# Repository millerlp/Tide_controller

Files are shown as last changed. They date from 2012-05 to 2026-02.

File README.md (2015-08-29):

Tide_controller
===============

Arduino code and associated files for building an aquarium tide height controller. This assumes that you 
have downloaded and installed the latest version of the Arduino software (v1.6.4, or newer).

Installation:

To operate the tide controller rack, install the following:

1. Install a copy of RTClib in your Arduino/libraries/ directory. If there is not already a libraries directory, create it now. RTClib can be downloaded from https://github.com/millerlp/RTClib. If the copy you download and unzip is called "RTClib-master", rename the folder to simply be "RTClib".

2. Copy the folder with the tide library for your site (i.e. TidelibSanDiegoSanDiegoBay) into Arduino/libraries/

3. Copy the Tide_controller_v2_5 folder (or most recent version) into your Arduino folder where 
your other sketches are normally stored. 

4. Open the Tide_controller sketch in the Arduino IDE, and make sure the correct tide site
library is referenced in the Initial Setup section, near line 57, with a line like:

	\#include "TidelibSanDiegoSanDiegoBay.h"

That line should contain the name of the library for your local site that you copied into Arduino/libraries/.

5. If you want to change the tide range in which the tide rack travels, you can change the
value for the upperPos on or around line 64, which looks like:
	float upperPos = 5.0;
That line represents the upper limit at which the tide rack will stop moving upward, even
if the predicted tide goes higher. The units of upperPos are feet (not meters or inches). 

Plug the Arduino in to the computer using a USB cable. Upload the program to the Arduino. 
Open the serial monitor to view the output. See the http://arduino.cc site for help with 
these steps. 

------------------------------
If the real time clock attached to the Arduino is not yet set, you need to set it one time
before loading the tide prediction software onto the Arduino. Open the Arduino software and 
go to File>Examples>RTClib>settime_exact.ino. Follow the instructions at the top of
that sketch to upload the correct time to your real time clock. Make sure the time you enter
is in your local standard time, not Daylight Savings Time (which runs Mar-Nov
in most places). The tide prediction routine relies on the time being set to local 
standard time for your site, otherwise you won't get the current tide height out. After running
the settime_exact.ino sketch, before unplugging the Arduino, immediately upload a different 
sketch (such as the Tide_controller sketch) to the Arduino so that the clock doesn't try to reset 
itself repeatedly when the Arduino restarts.

-------------------------------
If there is no folder containing a tide prediction library for your desired site, it
will be necessary to generate a library using the R scripts found in the 
Generate_new_site_libraries directory. The harmonic data for NOAA sites are all in
the Harmonics_20120302.Rdata file. With these data, you can generate a new library
by running the R script tide_harmonics_library_generator.R. Inside that file, you must
enter a name for the site you're interested in on the line
stationID = 'Monterey Harbor'
Change the value inside the quote marks to match your site, save the file, and run the
script in R. It will create a new directory with the necessary library files inside that
can be copied into the Arduino/libraries/ folder. Find the name for your site by looking 
through the XTide website http://www.flaterco.com/xtide/locations.html 
XTide only produces harmonics for 635 reference tide stations (all others are approximated 
from these tide stations), so you need to find the nearest station listed as "Ref" on that 
page, rather than "Sub" stations.

The other R scripts in the Generate_new_site_libraries directory could be used to make an
updated Rdata file when XTide updates the original harmonics database and after you
convert it to a text file using the libtcd library from the XTide site (see the notes inside
the R scripts).

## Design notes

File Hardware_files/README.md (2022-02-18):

Tide_controller/Hardware_files

A add-on 'shield' designed to be used with an Arduino Uno was designed for this
project. The shield provides mounting points for the real time clock (DS3231),
buttons, indicator LEDs, resistors, and connectors to interface with the stepper 
motor controller and displays. 

See the file 'Tide_shield_notes.pdf' for more information on how this shield
is meant to be wired and used. 

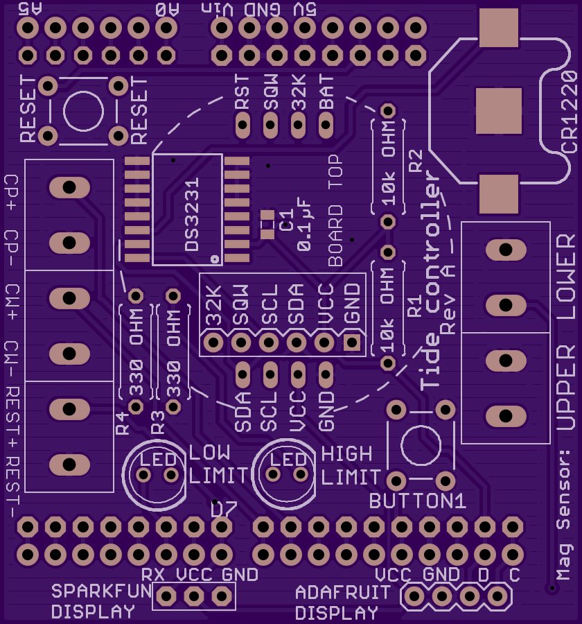
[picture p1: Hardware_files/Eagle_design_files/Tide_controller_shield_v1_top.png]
board image


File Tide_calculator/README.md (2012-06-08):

Tide_calculator.ino
Luke Miller, June 2012

This Arduino sketch is an example of a stand-alone tide height calculator. It doesn't 
do anything besides calculate a new tide height once per minute and output that
value to the Arduino's serial monitor (set your baud rate to 115200). This can 
be used as the basis for creating more complicated projects that need an 
accurate tide height calculation.

The calculations are only made for a single pre-programmed site, so if you need 
projections for a different NOAA tide site, you need to modify the Amplitude (Amp)
and Kappa arrays, preferrably using the R script files provided in the github 
repository. 

In addition to the basic Arduino, the only other required piece of hardware is a 
real time clock, based on the DS1307 or DS3231 chips, connected to analog pins
4 + 5 for the I2C interface (on traditional Arduinos such as the Uno). The routine
needs a current date and time to correctly make predictions. If used for sites outside
of the Pacific Standard Time zone, you'll also need to modify the value of adjustGMT 
inside the sketch.

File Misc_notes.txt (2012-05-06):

Arduino ports:

B: digital pin 8 to 13, covered by PCINT0
C: analog input pins, 	covered by PCINT1
D: digital pins 0 to 7, covered by PCINT2

Modified mySoftwareSerial.cpp to comment out lines:

/*
#if defined(PCINT1_vect)
ISR(PCINT1_vect)
{
  SoftwareSerial::handle_interrupt();
}
#endif

#if defined(PCINT2_vect)
ISR(PCINT2_vect)
{
  SoftwareSerial::handle_interrupt();
}
#endif

#if defined(PCINT3_vect)
ISR(PCINT3_vect)
{
  SoftwareSerial::handle_interrupt();
}
#endif
*/

so that mySoftwareSerial doesn't interfere with other routines trying to
use pin change interrupts on ports C and D. mySoftwareSerial retains use 
of pin change interrupts on port B (digital pins 8-13).
This leaves ports C and D available for routines like the PololuWheelEncoders.
See http://baldwisdom.com/we-interrupt-our-regular-programming/

The code in PololuWheelEncoders.cpp also needs to be modified. The line
ISR(PCINT0_vect) 
should be changed to read ISR(PNINT2_vect), and the two lines

ISR(PCINT1_vect,ISR_ALIASOF(PCINT0_vect));
ISR(PCINT2_vect,ISR_ALIASOF(PCINT0_vect));

below that should be commented out. This will make it so that the encoder
functions only work on digital lines 0-7 (Arduino PortB).

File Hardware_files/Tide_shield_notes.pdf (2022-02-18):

A design for a printed circuit board to mount to a standard Arduino Uno microcontroller is provided here. This is often referred to as a “shield”. The design files were created with Cadsoft Eagle 7.2, and be found in the online archive associated with this project,

### http://purl.stanford.edu/rb471wt3944 as the compressed archive

“Tide_controller_circuit_board_files.tar”. The Eagle files can be used to generate files that many online printed circuit board manufacturers can use to produce this board.

The shield is designed to interface with a CW230 stepper motor controller, two magnetic reed switches, and a real time clock. There are three different options available for real time clocks on the shield, depending on the user’s desire and available parts. Two places for indicator LEDs are provided, along with buttons to reset the Arduino and a button to control the tide rack behavior (BUTTON1). The individual parts are indicated in the following sections.


Figure 1. The top side of the tide controller shield.

## Connectors for CW230 stepper motor controller and magnetic reed switches

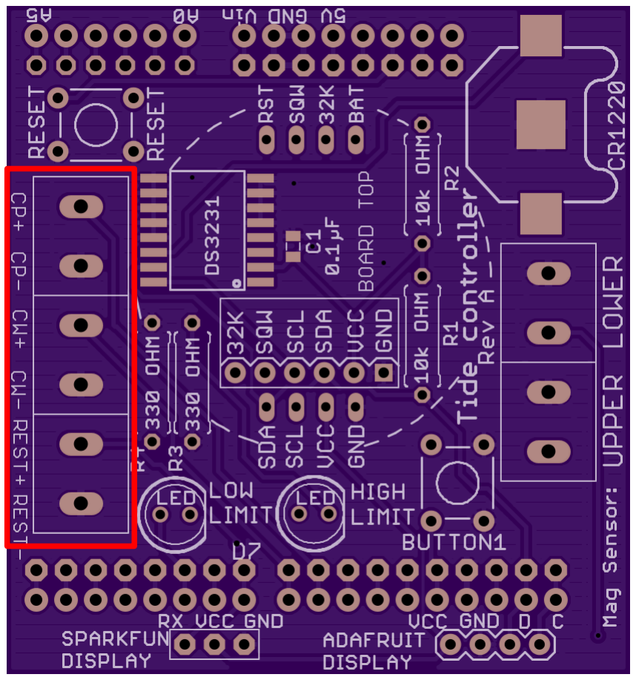
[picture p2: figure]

Figure 2. Positions for terminal blocks (highlighted in red) are provided to hook wires to the CW230 stepper motor controller. The labels here match the labels used on the CW230.

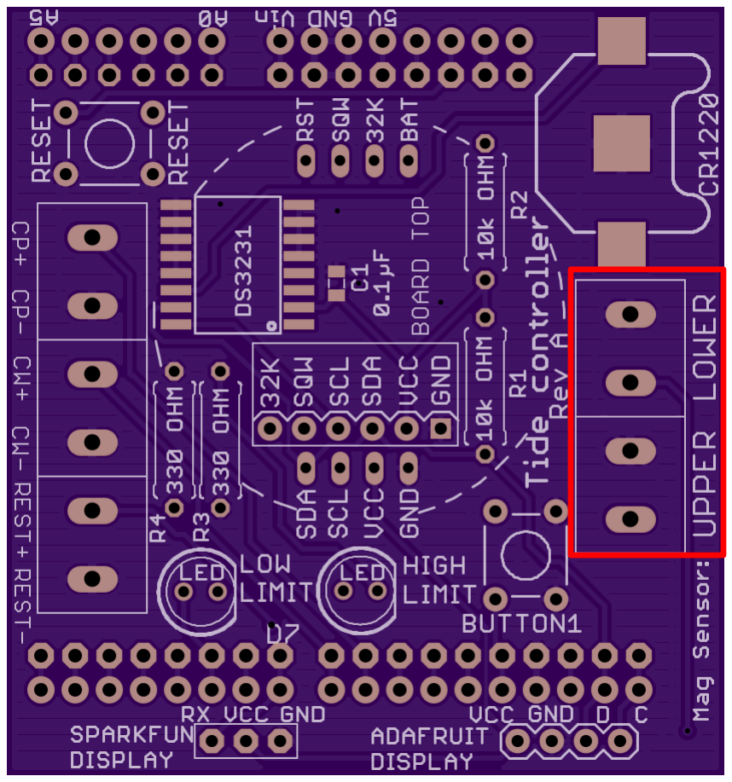
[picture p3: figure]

Figure 3. Positions for terminal blocks (highlighted in red) are provided to hook wires to two separate magnetic reed switches to be mounted on the frame of the tide rack. These set the upper and lower travel limits of the rack carriage, and are actuated by a magnet attached to the rack carriage. The polarity of the wires on these terminals does not matter, they are simple open/closed switches.

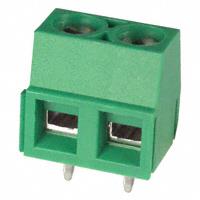
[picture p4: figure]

Figure 4. Terminal blocks that will fit in the shield. These are available from several manufacturers. The pictured unit is from On Shore Technology Inc, part number EDZ250/2.

## LED indicators

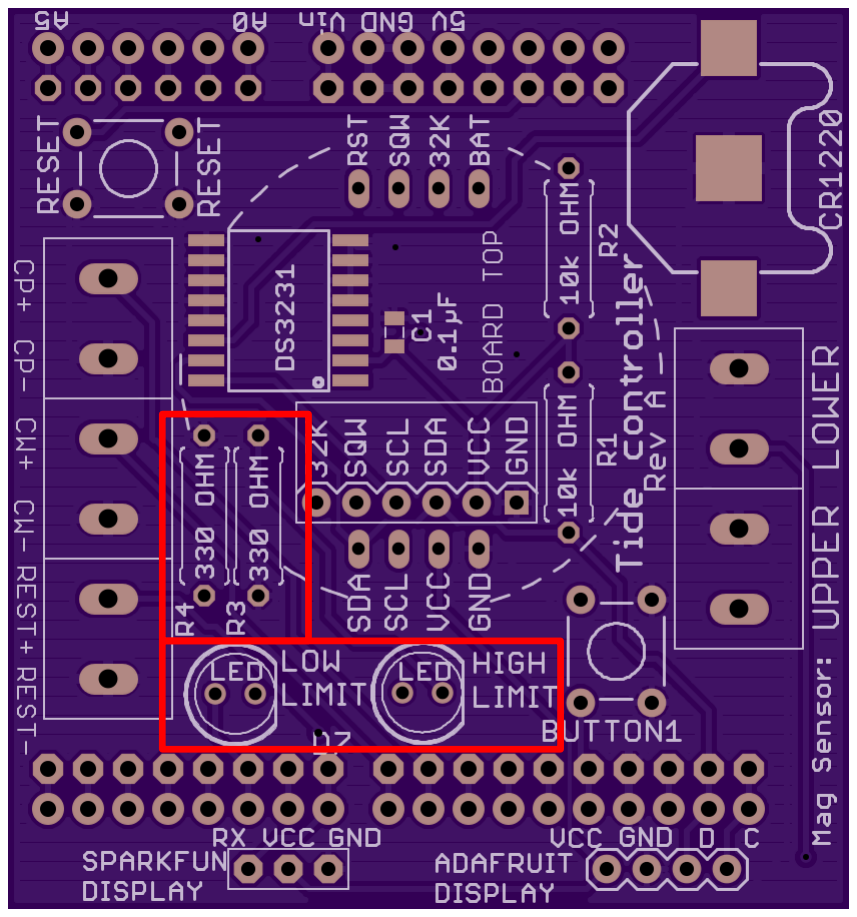
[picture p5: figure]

Figure 5. Positions for two LEDs, and their associated resistors are highlighted in red. A resistor value between 100ohm and 330ohm is sufficient. The LEDs fit standard 5mm (T 1-3/4) size LEDs. The low limit or high limit LED lights when the associated magnetic limit switch is activated. LED options from Lite-On include a red version LTL-307EE and a green version LTL-307GE. Resistors can be generic, such as Stackpole CF18JT330R 330 ohm 1/8Watt.

## Buttons

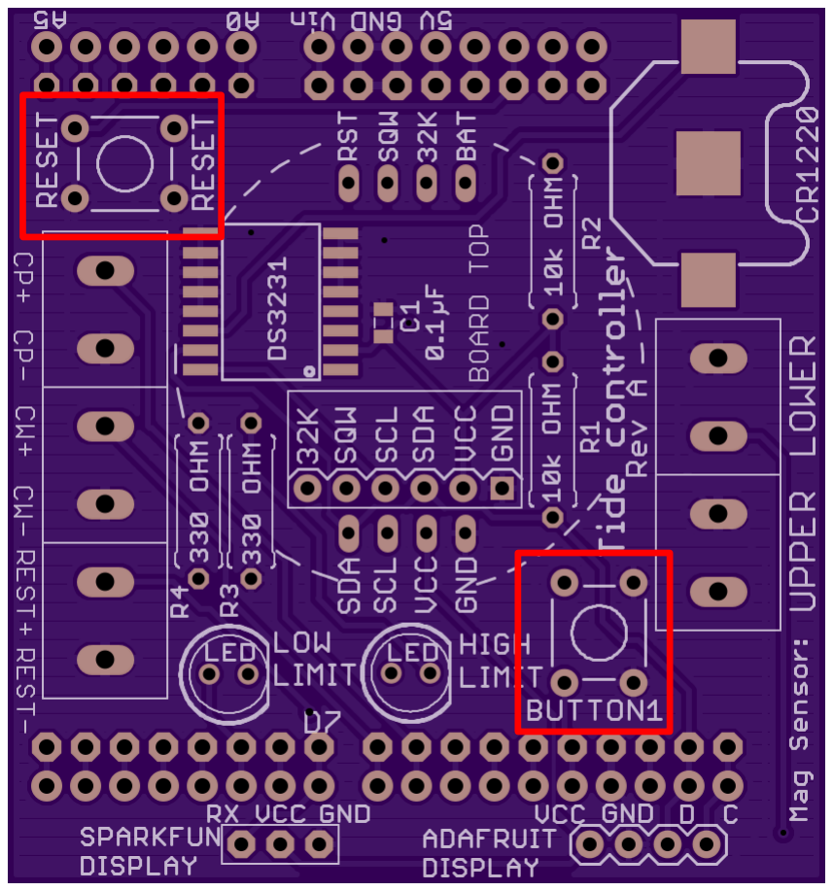
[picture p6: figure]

Figure 6. Button (also referred to as a “tactile switch”) mounting points are highlighted in red. The upper left position is a reset button for the Arduino, this duplicates the reset button found on Arduino boards and is not strictly necessary. The second button, labeled BUTTON1, along with the associated Arduino tide controller software, will cause the rack carriage to travel downwards until the user releases the button or the rack carriage activates the lower magnetic limit switch.

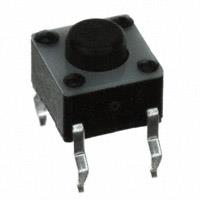
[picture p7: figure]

Figure 7. A standard tactile switch. These are available from many manufacturers. One common part is TE Connectivity part number 1825910-6.

## Real time clock options

There are three potential methods for mounting a real time clock on the shield. All three involve the use of a DS3231S real time clock from Maxim.

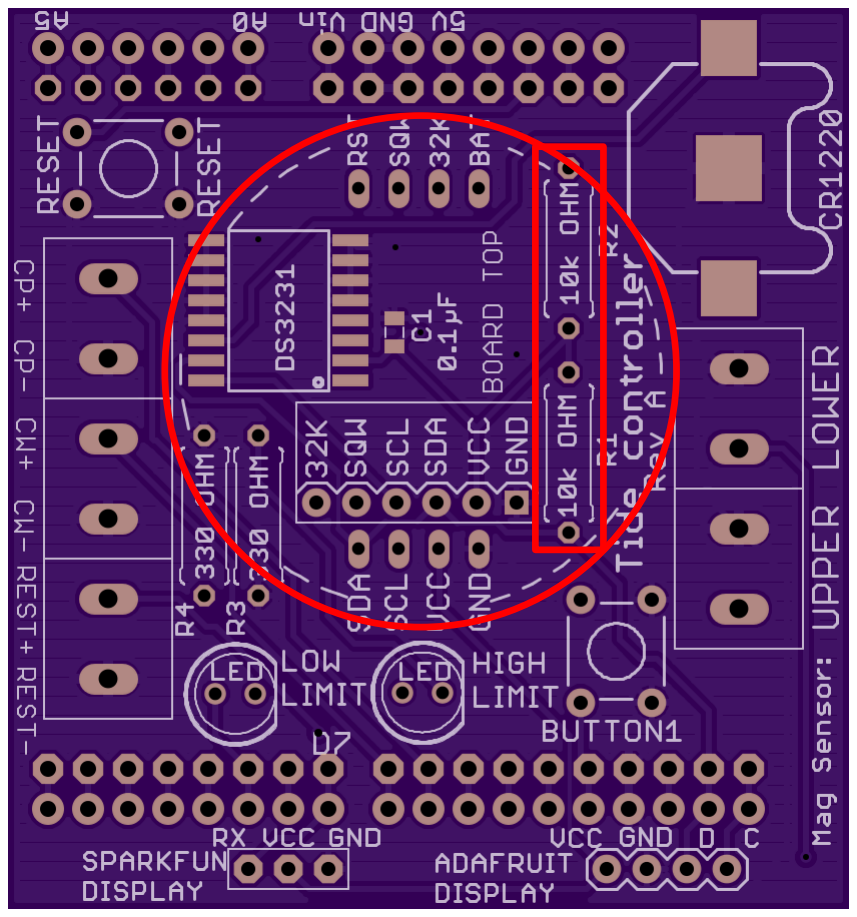
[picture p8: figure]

Figure 8. The circled region indicates where a Chronodot real time clock can mount, with hole labels that match the labels on a Chronodot. Two positions for additional required 10,000 ohm resistors are indicated in the boxed region.

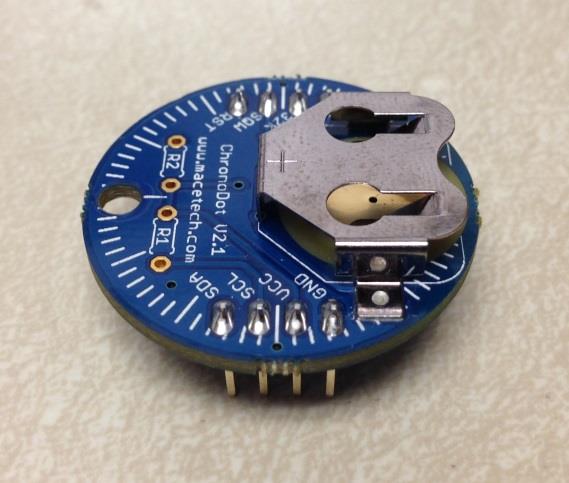
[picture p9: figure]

Figure 9. A Chronodot real time clock based on the DS3231S. Available from online vendors such as Macetech.com and Adafruit.com. The Chronodot also provides mounting positions for 10,000 ohm resistors, the user only needs to install resistors on the shield or on the Chronodot, but not both. If you use the Chronodot, you may also wish to install two 4-position female headers to make it removable, such as part number Sullins PPPC041LFBN-RC.

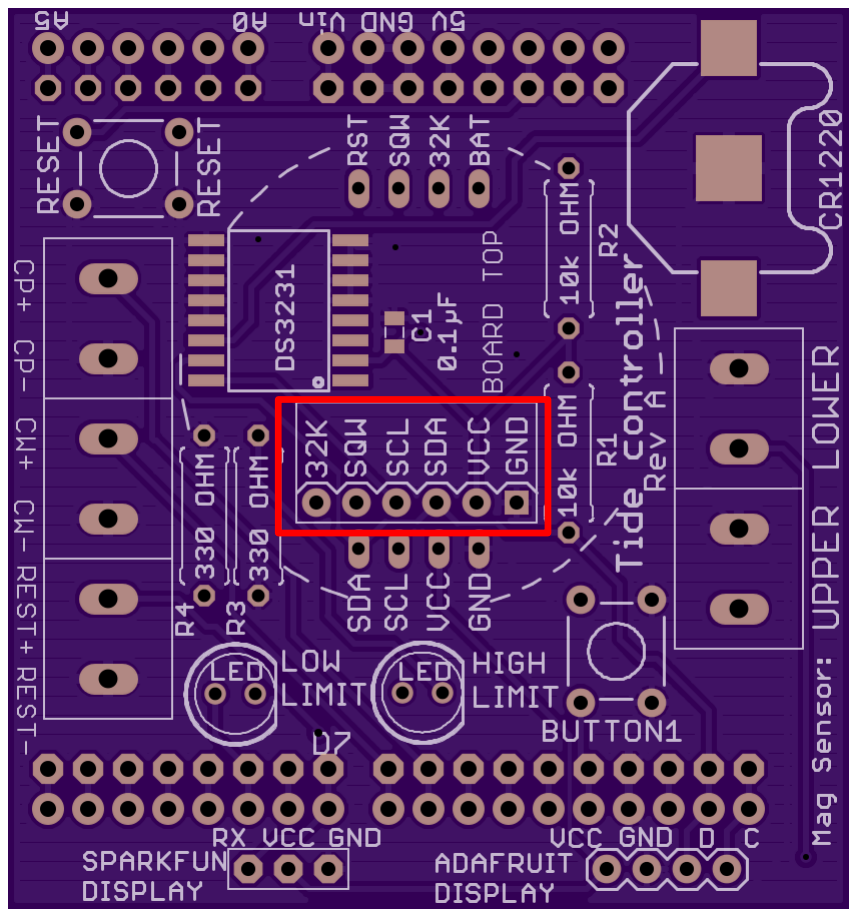
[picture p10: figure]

Figure 10. Mounting holes for a generic DS3231 + AT24C32 module. The hole labels match the labels on the module.

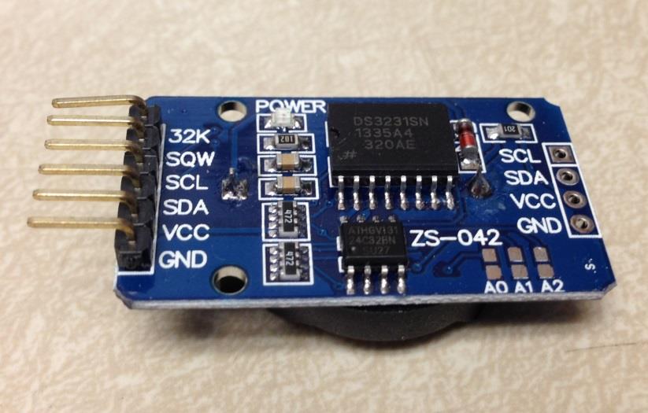
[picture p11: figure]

Figure 11. A DS3231 + AT24C32 module. These are a generic part available from a number of online vendors.

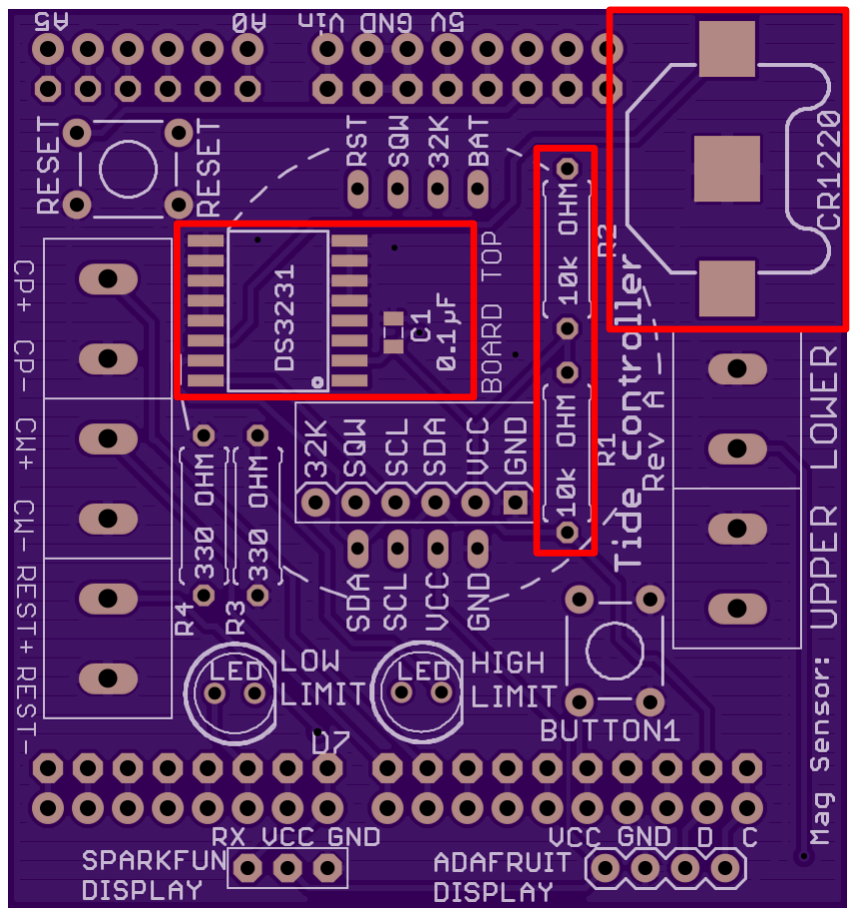
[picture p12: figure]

Figure 12. For users comfortable with surface mount soldering, a bare DS3231S chip (Maxim Integrated) may be mounted on the indicated footprint, along with a 0.1µF ceramic capacitor in a standard 0805 footprint (various vendors, for example part number 399-1168-1-ND from Digikey), and a CR1220 3V lithium battery holder (Keystone Electronics part number 3000). In this configuration, the user will also need to install the two 10,000 ohm resistors (for example, Stackpole CF18JT10K0).

## Mounting pins

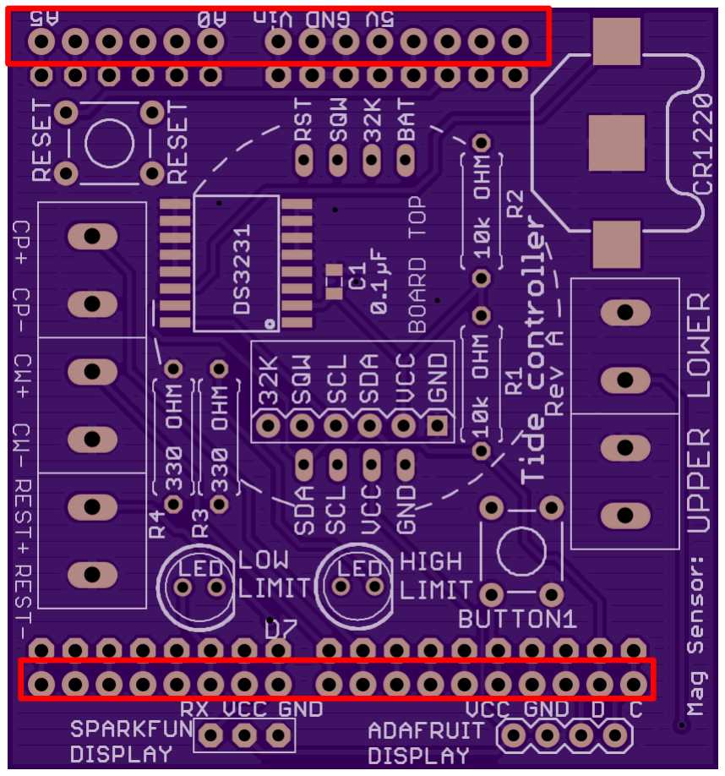
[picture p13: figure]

Figure 13. To mount the shield to an Arduino board, install header pins on the bottom side of the board in the indicated rows of holes. These will match up with the female headers on the top of an Arduino board. The adjacent rows of pin holes to the inside of the indicate boxes are provided so the user can access the other Arduino pins if necessary. Example: TE Connectivity 4-103185-0, Digikey PN A26513-40-ND.

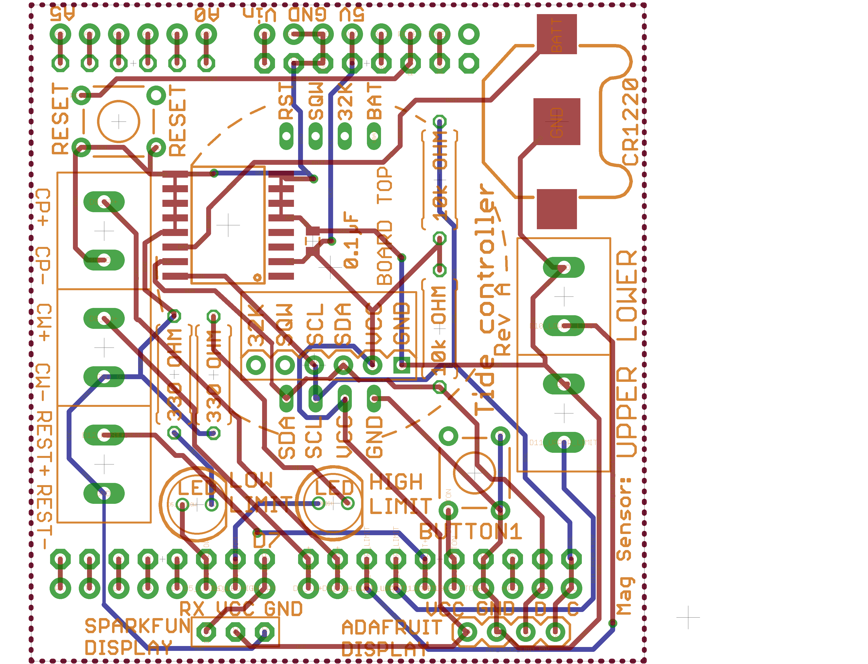
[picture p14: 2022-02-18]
Hardware_files/Eagle_design_files/Board_layout.png

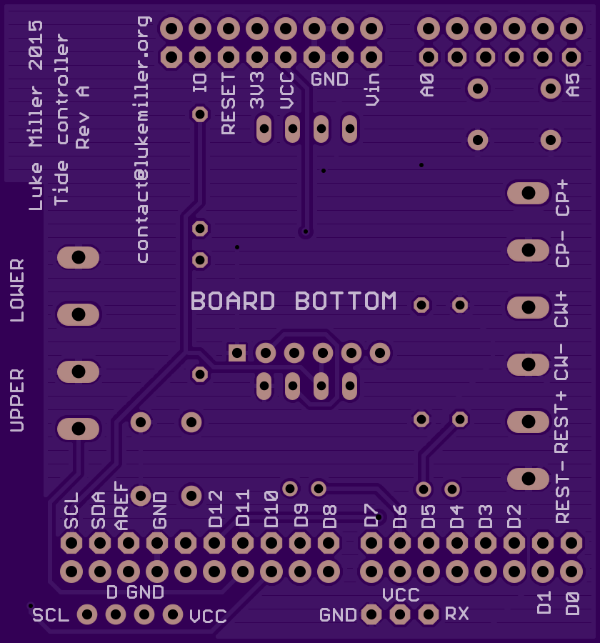
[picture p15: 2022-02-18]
Hardware_files/Eagle_design_files/Tide_controller_shield_v1_bottom.png

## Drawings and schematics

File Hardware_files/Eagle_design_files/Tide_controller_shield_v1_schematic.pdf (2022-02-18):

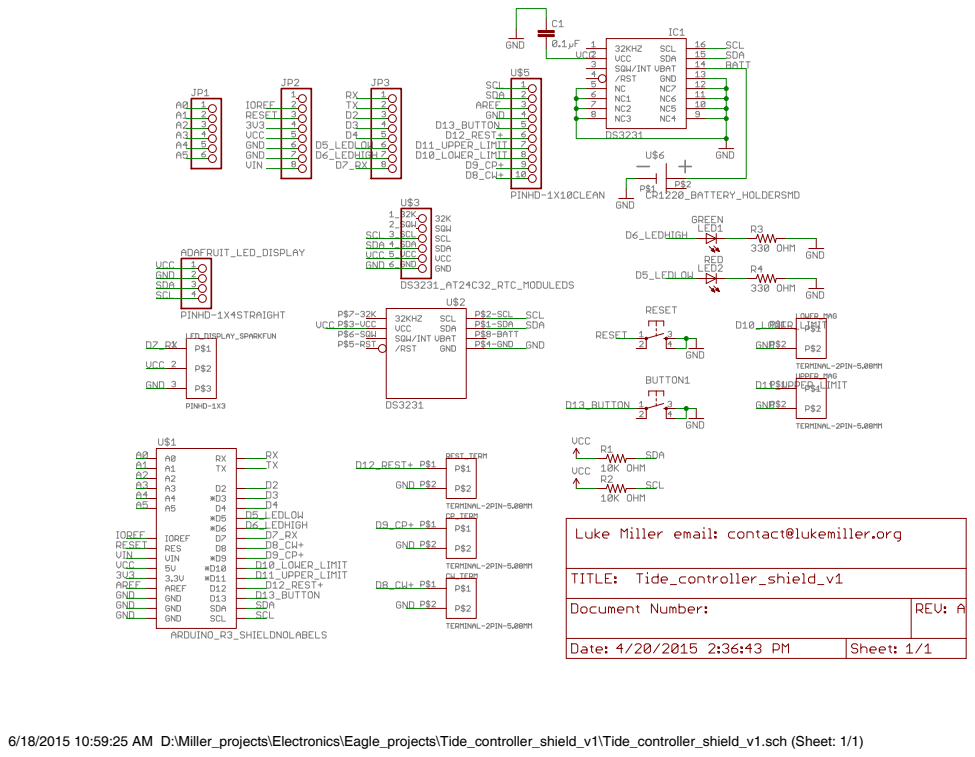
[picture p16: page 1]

6/18/2015 10:59:25 AM D:\Miller_projects\Electronics\Eagle_projects\Tide_controller_shield_v1\Tide_controller_shield_v1.sch (Sheet: 1/1)

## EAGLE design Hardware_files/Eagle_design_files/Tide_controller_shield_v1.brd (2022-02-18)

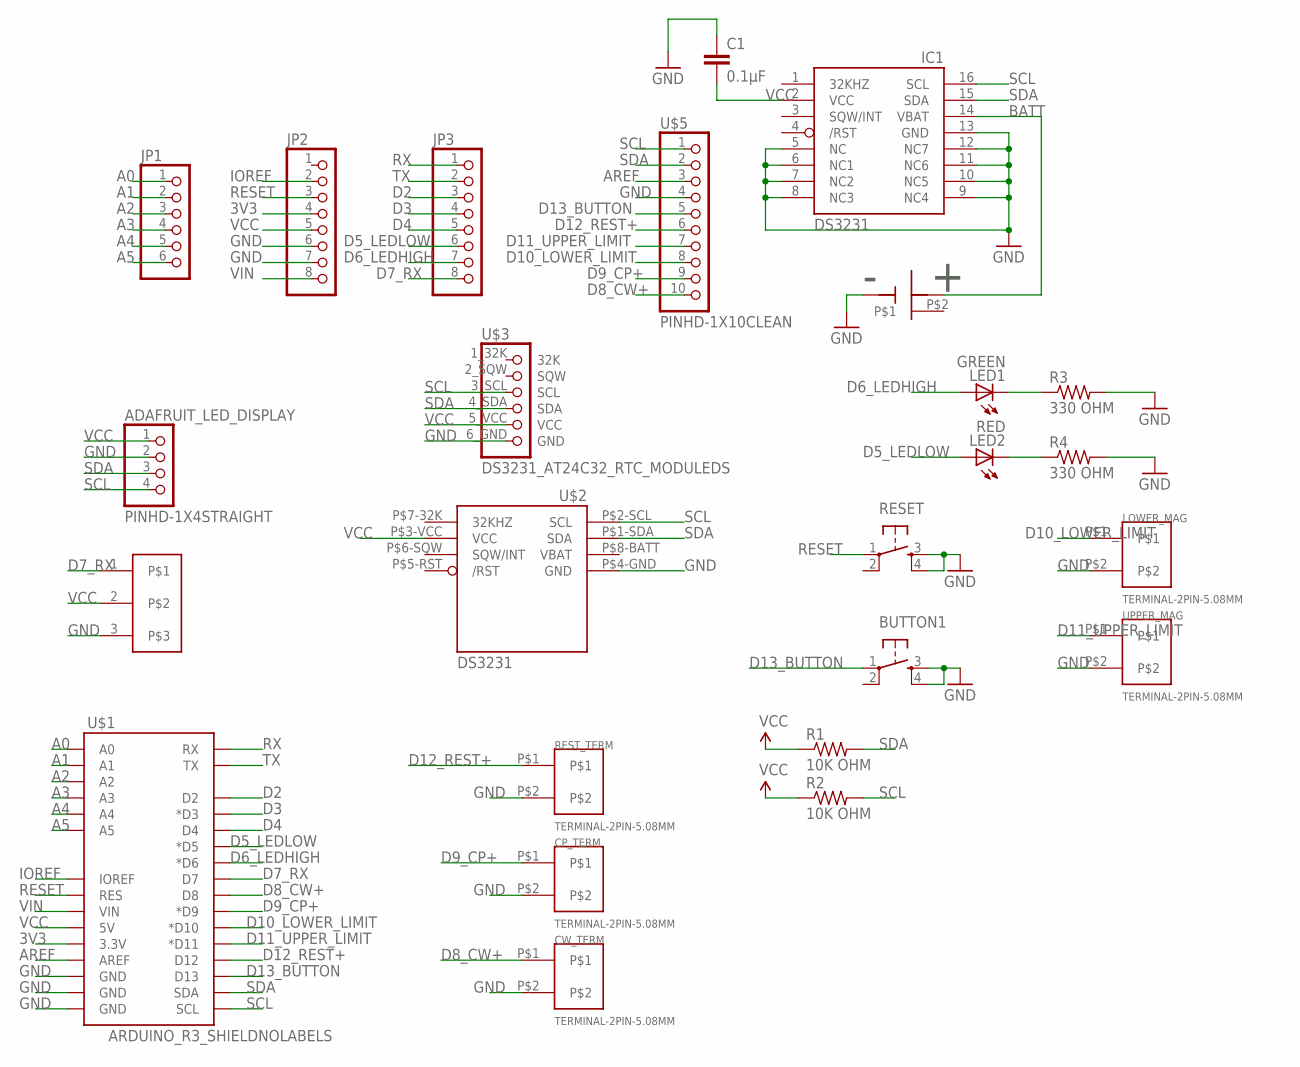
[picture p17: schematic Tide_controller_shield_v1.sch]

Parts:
ADAFRUIT_LED_DISPLAY: PINHD-1X4STRAIGHT; 1X04
BUTTON1: PUSHBUTTON-DPST-PTH; SWITCH-TACTILE-PTH-DPST
C1: 0.1µF; 0805
CP_TERM: TERMINAL-2PIN-5.08MM
CW_TERM: TERMINAL-2PIN-5.08MM
IC1: DS3231/SO; SO16W
JP1: PINHD-1X6CLEAN; 1X06-CLEAN
JP2, JP3: PINHD-1X8CLEANBIG; 1X08-CLEANBIG
LED1: GREEN; LED5MM
LED2: RED; LED5MM
LED_DISPLAY_SPARKFUN: PINHD-1X3; 1X03
LOWER_MAG: TERMINAL-2PIN-5.08MM
R1, R2: 10K OHM; 0309/10
R3, R4: 330 OHM; 0309/10
RESET: PUSHBUTTON-DPST-PTH; SWITCH-TACTILE-PTH-DPST
REST_TERM: TERMINAL-2PIN-5.08MM
U$1: ARDUINO_R3_SHIELDNOLABELS; UNO_R3_SHIELD_NOLABELS
U$2: CHRONODOT-OUTLINE
U$3: DS3231_AT24C32_RTC_MODULEDS; DS3231_AT24C32_RTC_MODULE
U$5: PINHD-1X10CLEAN; 1X10-CLEANBIG
U$6: CR1220_BATTERY_HOLDERSMD; CR1220_BATTERY_HOLDER_SMD
UPPER_MAG: TERMINAL-2PIN-5.08MM

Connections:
3V3: JP2.4, U$1.3.3V
A0: JP1.1, U$1.A0
A1: JP1.2, U$1.A1
A2: JP1.3, U$1.A2
A3: JP1.4, U$1.A3
A4: JP1.5, U$1.A4
A5: JP1.6, U$1.A5
AREF: U$1.AREF, U$5.3
BATT: IC1.14 (VBAT), U$6.P$1 (VBAT)
D2: JP3.3, U$1.D2
D3: JP3.4, U$1.D3 (*D3)
D4: JP3.5, U$1.D4
D5_LEDLOW: JP3.6, LED2.A, U$1.D5 (*D5)
D6_LEDHIGH: JP3.7, LED1.A, U$1.D6 (*D6)
D7_RX: JP3.8, LED_DISPLAY_SPARKFUN.1, U$1.D7
D8_CW+: CW_TERM.P$1, U$1.D8, U$5.10
D9_CP+: CP_TERM.P$1, U$1.D9 (*D9), U$5.9
D10_LOWER_LIMIT: LOWER_MAG.P$1, U$1.D10 (*D10), U$5.8
D11_UPPER_LIMIT: U$1.D11 (*D11), U$5.7, UPPER_MAG.P$1
D12_REST+: REST_TERM.P$1, U$1.D12, U$5.6
D13_BUTTON: BUTTON1.1, U$1.D13, U$5.5
GND: ADAFRUIT_LED_DISPLAY.2, BUTTON1.3, BUTTON1.4, C1.1, CP_TERM.P$2, CW_TERM.P$2, IC1.5 (NC), IC1.6 (NC1), IC1.7 (NC2), IC1.8 (NC3), IC1.9 (NC4), IC1.10 (NC5), IC1.11 (NC6), IC1.12 (NC7), IC1.13 (GND), JP2.6, JP2.7, LED_DISPLAY_SPARKFUN.3, LOWER_MAG.P$2, R3.2, R4.2, RESET.3, RESET.4, REST_TERM.P$2, U$1.GND@0 (GND), U$1.GND@1 (GND), U$1.GND@2 (GND), U$2.P$4-GND (GND), U$3.6_GND (GND), U$5.4, U$6.GND, UPPER_MAG.P$2
IOREF: JP2.2, U$1.IOREF
unnamed: LED1.K (C), R3.1
unnamed: LED2.K (C), R4.1
RESET: JP2.3, RESET.1, U$1.RES
RX: JP3.1, U$1.RX
SCL: ADAFRUIT_LED_DISPLAY.4, IC1.16 (SCL), R2.2, U$1.SCL, U$2.P$2-SCL (SCL), U$3.3_SCL (SCL), U$5.1
SDA: ADAFRUIT_LED_DISPLAY.3, IC1.15 (SDA), R1.2, U$1.SDA, U$2.P$1-SDA (SDA), U$3.4_SDA (SDA), U$5.2
TX: JP3.2, U$1.TX
VBAT: U$2.P$8-BATT (VBAT)
VCC: ADAFRUIT_LED_DISPLAY.1, C1.2, IC1.2 (VCC), JP2.5, LED_DISPLAY_SPARKFUN.2, R1.1, R2.1, U$1.5V, U$2.P$3-VCC (VCC), U$3.5_VCC (VCC)
VIN: JP2.8, U$1.VIN

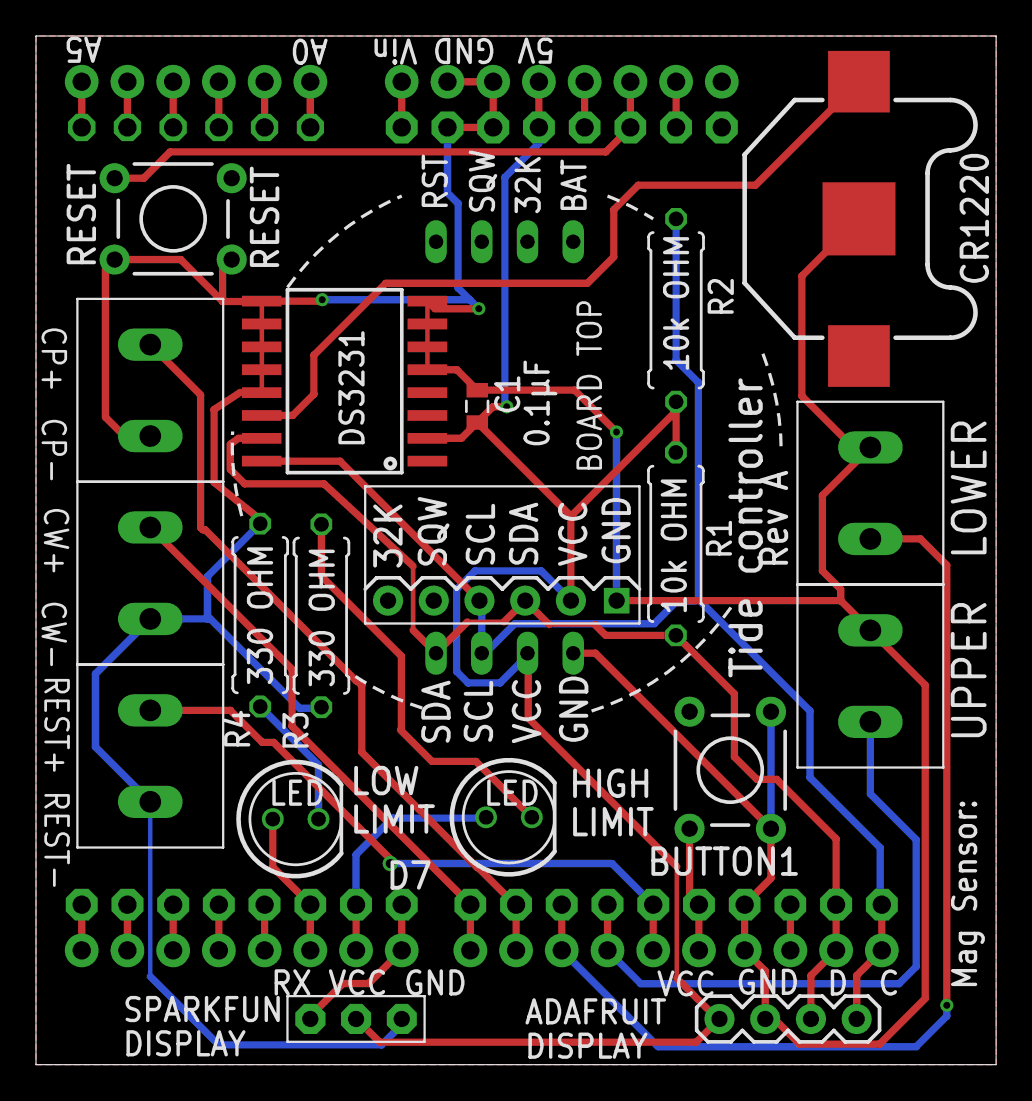
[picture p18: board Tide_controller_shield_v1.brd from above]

Board: 2 copper layers, 53.3 x 57.1 mm, 25 parts (0 on the bottom side), 32 nets.

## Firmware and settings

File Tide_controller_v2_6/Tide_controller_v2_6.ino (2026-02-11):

/* Tide_controller_v2.6
  Copyright (C) 2015 Luke Miller (last updated 2026-02-11)
 This version is set up to work on a lead-screw driven rack that has
 a limited travel range. There should be a limit switch at each end 
 of the rack's travel, and the distance between the values for 
 upperPos and lowerPos must be equal to the distance between those 
 limit switches. Designed to work with daughterboard rev 8 and the
 CW230 stepper driver, 36V power supply, and 57BYGH405A stepper motor.
 
 Copyright (C) 2015 Luke Miller
 
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
 
 This program is designed to calculate the current tide height
 and control a motor that changes the water level in a tank.
 
 Written under v1.0.5 of the Arduino IDE.
 Updated to work under v1.8.19 
 
 The harmonics constants for the tide prediction are taken from 
 the XTide harmonics file. The original harmonics.tcd file is 
 available at 
 http://www.flaterco.com/xtide/files.html
 As with XTide, the predictions generated by this program should
 not be used for navigation, and no accuracy or warranty is given
 or implied for these tide predictions. Hell, the chances are 
 pretty good that the tide predictions generated here are 
 completely wrong.
 
 
*/
//********************************************************************************

// Initial setup
//*******************************
// Header files for talking to real time clock
#include <Wire.h>
#include <SPI.h>  // Required for RTClib to compile properly
#include <RTClib.h> // From https://github.com/millerlp/RTClib
#include <SoftwareSerial.h>
// Real Time Clock setup
RTC_DS3231 RTC;     // Uncomment this version if you use the new DS3231 clock 
// RTC_DS1307 RTC;  // Uncomment this version if you use the older DS1307 clock

// Tide calculation library setup
//#include "TideMontereyHarborlib.h"
#include "TidelibSanDiegoSanDiegoBay.h"
TideCalc myTideCalc;  // Create TideCalc object called myTideCalc 


//-----------------------------------------------------------------------------
// ************** HERE IS THE ONLY VALUE YOU NEED TO CHANGE ***************
// ************** HERE IS THE ONLY VALUE YOU NEED TO CHANGE ***************
float upperPos = 2.42; // Upper limit, located at upperLimitSwitch. Units = ft.
// ************** THAT WAS THE ONLY VALUE YOU NEED TO CHANGE ***************
// ************** THAT WAS THE ONLY VALUE YOU NEED TO CHANGE ***************
// So what does changing upperPos do? It sets the maximum tide height that you
// want the tide rack to halt at. Here's an example:
// If you want to recreate the conditions of a mud flat that
// sits at 4.5 ft above the zero tide level, you want the tide rack to travel
// above that height to fully submerge the mud in your tank. We'll round up
// to 5.0 ft for upperPos, so that any high tide above 4.5ft will submerge the
// mud in the tank, up to a depth of 6 inches above the mud.
// (4.5ft + 6 inches = 5.0ft). If the predicted tide goes above 5.0ft, the tide
// rack will hold at its upper travel limit, leaving the mud submerged until 
// the tide drops back below the upperPos value. This all assumes that you have
// set up the tide rack and tank so that the upper travel limit of the tide rack
// is six inches above the mud level in your tanks. 
// ----------------------------------------------------------------------------
// Do not change the value of lowerPos. It is set to accommodate the travel
// limits of the tide rack, which has roughly 2.75 ft between the upper and 
// lower travel limits. (Updated 2015-03 to 2.0 ft, assumes upper sensor was moved down)
float lowerPos = upperPos - 2.0; // Lower limit, located at lowerLimitSwitch, units = ft.
// The value for upperPos is taken to be the "home" position, so when ever the
// upperLimitSwitch is activated, the motor is at exactly the value of upperPos.
// In contrast, the value of lowerPos can be less precise, it is just close to 
// the position of where the lowerLimitSwitch will activate, and is used as a 
// backup check to make sure the rack doesn't exceed its travel limits. The 
// lowerLimitSwitch is the main determinant of when the motor stops downward
// travel. This is mainly to accommodate the use of magnetic switches where the
// precise position of activation is hard to determine without lots of trial 
// and error.
float currPos;  // Current position, within limit switch range.    Units = ft.
float results;  // results holds the output from the tide calc.    Units = ft.

int currMinute; // Keep track of current minute value in main loop

//****** 7 Segment LED display setup
#define txPin 7
#define rxPin 4 // not used, but must be defined
SoftwareSerial mySerial = SoftwareSerial(rxPin, txPin);

//---------------------------------------------------------------------------------------
/*  Stepper motor notes
  This uses a CW230 3amp 2-phase stepper motor drive with 5V TTL inputs, 
  sourced from http://www.mpja.com/Stepper-Motor-Driver-3A-Max-CW230/productinfo/17451%20MS/
  originally. This takes two main inputs, a direction input CW+, and a step
  input, CP+. The direction is set by pulling the direction pin CW+ high or low. 
  A single step is taken by pulling the step pin CP+ high. There is also 
  a REST pin on the CW230, which kills power to the motor (saving power
  and heat). 
  The other CW230 pins REST-, CP- and CW- should all be tied to the
  Arduino's ground. 
  The CW230 uses tiny DIP switches to set the microstepping mode. For
  1/16th microsteps, switches 1 + 2 need to be flipped up (opposite the
  arrow on the switch panel), while switch 3 needs be flipped down (same
  as the arrow direction on the switch panel). 
 */
const byte stepperDir = 8;  // define stepper direction pin. Connect to 
// CW230 CW+ pin
const byte stepperStep = 9; // define stepper step pin. Connect to 
// CW230 CP+ pin
const byte stepperEnable = 12; // define motor driver enable pin
// Connect to CW230 REST+ pin. Pull high to shut off motor
// The CW230 pins REST-, CP-, and CW- should all be attached to Arduino ground.

const int stepDelay = 120; // define delay between steps of the motor. This
// affects the speed at which the motor will turn. Units are microseconds
// For microstepping 1/16 steps, use a value around 200. For full step mode,
// the delay needs to be lengthened to around 5000. 
//*******************************

//-----------------------------------------------------------------------------
// Conversion factor, feet per motor step
// Divide desired travel (in ft.) by this value
// to calculate the number of steps that
// must occur.
const float stepConv = 0.000002604;   // Value for 10 tpi lead screw, microstep
/*  10 tooth-per-inch lead screw = 0.1 inches per revolution
 0.1 inches per rev / 12" = 0.008333 ft per revolution
 0.008333 ft per rev / 3200 steps per rev = 0.000002604 ft per step
 Assumes a 200 step per rev stepper motor being controlled in 1/16th
 microstepping mode ( = 3200 steps per revolution).
 We're using feet here because the tide prediction routine outputs
 tide height in units of feet. 
 */

float heightDiff;    // Float variable to hold height difference, in ft.                                    
long stepVal = 0;     // Store the number of steps needed
// to achieve the new height


//---------------------------------------------------------------------------
// Define the digital pin numbers for the limit switches. These will be 
// wired to one lead from a magentic reed switch. The 2nd lead from each reed 
// switch will be wired to ground on the Arduino.
const byte lowerLimitSwitch = 10;
const byte upperLimitSwitch = 11;
// Define digital pin number for the overrideButton
// Pressing this button will run the carriage down, until it hits the lower 
// limit switch
const byte overrideButton = 13; 

// Define highLimitLED and lowLimitLED pins
const byte lowLimitLED = 5;  // On digital pin 5
const byte highLimitLED = 6; // On digital pin 6


//**************************************************************************
// Welcome to the setup loop
void setup(void)
{  
  Wire.begin();
  RTC.begin();
  //--------------------------------------------------
  pinMode(stepperDir, OUTPUT);   // direction pin for Big Easy Driver
  pinMode(stepperStep, OUTPUT);  // step pin for Big Easy driver. One step per rise.
  pinMode(stepperEnable, OUTPUT); // enable pin for Big Easy driver motor power
  digitalWrite(stepperDir, LOW);
  digitalWrite(stepperStep, LOW);
  digitalWrite(stepperEnable, HIGH); // turns off motor power when high  

  // Set up switches and input button as inputs. 
  pinMode(lowerLimitSwitch, INPUT_PULLUP);
  pinMode(upperLimitSwitch, INPUT_PULLUP);
  pinMode(overrideButton, INPUT_PULLUP);
  // When using the internal pull-up resistors for the switches above, the
  // default state for the input pin is HIGH (+5V), and goes LOW (0V) when
  // the switch/button connects to ground. Thus, a LOW value indicates that the
  // button or switch has been activated. 
  
  // Set LED pins as outputs.
  pinMode(lowLimitLED, OUTPUT);
  digitalWrite(lowLimitLED, LOW);
  pinMode(highLimitLED, OUTPUT);
  digitalWrite(highLimitLED, LOW);
  
  // For debugging output to serial monitor
  Serial.begin(115200);
  //************************************
  DateTime now = RTC.now();
  currMinute = now.minute(); // Store current minute value
  printTime(now);  // Call printTime function to print date/time to serial
  Serial.println("Calculating tides for: ");
  Serial.println(myTideCalc.returnStationID());
  // Calculate current tide height
  results = myTideCalc.currentTide(now);
  
  // Set up 7-segment display
  pinMode(txPin, OUTPUT);
  mySerial.begin(9600);
  mySerial.print("v"); // reset display
  mySerial.print("z"); // command byte for brightness control
  mySerial.write(254); // Set display brightness (1 - 254)
	// Update the 7-seg LED display. This will briefly show
	// the year, month, date, and then time in succession, followed by
	// going back to the current tide height. 
  sevenSegDisplayScrollDateTime(now); // function to print date + time to 7-seg display
  delay(1000);
	mySerial.write(0x76); // reset position to start
	mySerial.write("tidE");// spell "tidE" on 7-segment display
	delay(1000);
  sevenSegDisplay(results); // function to print result to 7-segment display
  delay(4000);
  
  //************************************
  // Spin motor to position rack at the home position (at upperLimitSwitch)
  // The while loop will continue until the upperLimitSwitch is activated 
  // (i.e. driven LOW). 
  Serial.println("Returning to upper limit");
  digitalWrite(stepperEnable, LOW); // turn motor power on
  delay(100);  
  while (digitalRead(upperLimitSwitch) != LOW) {
    // Set motor direction, HIGH = clockwise = up
    digitalWrite(stepperDir, HIGH);
    // Move stepper a single step
    digitalWrite(stepperStep, HIGH);
    delayMicroseconds(1);
    digitalWrite(stepperStep, LOW);
    delayMicroseconds(stepDelay);
  }
  digitalWrite(highLimitLED, HIGH); // turn on upper limit LED
  digitalWrite(stepperEnable, HIGH); // turn motor power off  
  currPos = upperPos; // currPos should now equal upperPos
  Serial.print("Current position: ");
  Serial.print(currPos);
  Serial.println(" ft.");
  delay(5000); // pause 5 seconds
  //  Lower carriage to proper height
  // Calculate distance to current tide height
  heightDiff = results - currPos;       // Units of feet.
  Serial.print("Current tide: ");
  Serial.print(results);
  Serial.println(" ft.");
  Serial.print("Height diff: ");
  Serial.print(heightDiff);
  Serial.println(" ft.");
  stepVal = (long)(heightDiff / stepConv); // convert to motor steps
  if (stepVal < 0) stepVal = -stepVal; // convert negative values
  // If the heightDiff is negative (carriage needs to drop) and the
  // upperLimitSwitch is activated (carriage is at home), move down.
  // This will ignore the case where the current tide height is lower
  // than the programmed lower travel limit. 
  if ( (heightDiff < 0) & (digitalRead(upperLimitSwitch) == LOW)) {
      Serial.println("Lowering...");
      digitalWrite(highLimitLED, LOW); // turn off upper limit LED
      digitalWrite(stepperEnable, LOW); // turn motor power on
      delay(100);      
      // Set motor direction to move downward
      digitalWrite(stepperDir, LOW); // LOW = counterclockwise = down     
      // Run motor the desired number of steps
      for (long steps = 0; steps < stepVal; steps++) {
        digitalWrite(stepperStep, HIGH);
        delayMicroseconds(2);
        digitalWrite(stepperStep, LOW);
        delayMicroseconds(stepDelay);
        // check lowerLimitSwitch each step, quit if activated
        if (digitalRead(lowerLimitSwitch) == LOW)  {
          // Update current position value
          currPos = currPos - (steps * stepConv);
          Serial.println("Hit lower limit switch");
          digitalWrite(lowLimitLED, HIGH); // turn on lowLimitLED
          break;  // break out of for loop
        }
      }
      // If the lowerLimitSwitch wasn't activated, then the motor
      // stopped above the limit switch. Set currPos to whatever
      // value is in 'results' currently. 
      if (digitalRead(lowerLimitSwitch) == HIGH) {  //switch not triggered
        currPos = results; // set currPos equal to current tide height
      }
      digitalWrite(stepperEnable, HIGH); // turn motor power off     
  }
  // Signal that main loop is starting
  mySerial.write(0x76); // reset position to start
  mySerial.write("RUn");// spell "Run" on 7-segment display
  
  Serial.print("Current position: ");
  Serial.print(currPos,2);
  Serial.println(" ft.");
  delay(5000);
}  // End of setup loop.

//**************************************************************************
// Welcome to the Main loop
void loop(void)
{
  // Get current time, store in object 'now'
  DateTime now = RTC.now();

  // If it is the start of a new minute, calculate new tide height and
  // adjust motor position
  if (now.minute() != currMinute) {
    // If now.minute doesn't equal currMinute, a new minute has turned
    // over, so it's time to update the tide height. We only want to do
    // this once per minute. 
    currMinute = now.minute();                   // update currMinute

    
    Serial.println();
    printTime(now);
    Serial.print("Previous tide ht: ");
    Serial.print(results,4);
    Serial.println(" ft.");   
    Serial.print("Previous position: ");
    Serial.print(currPos);
    Serial.println(" ft.");
    // Calculate new tide height based on current time
    results = myTideCalc.currentTide(now);
	  // Signal that main loop is starting
	
	
	// Show the year, month, date, and then time in succession
	sevenSegDisplayScrollDateTime(now); // function to print date + time to 7-seg display
	delay(750);
	mySerial.write(0x76); // reset led display position to start
	mySerial.write("tidE");// spell "tidE" on 7-segment display
	delay(1000);
	// Show the new calculated tide height
    sevenSegDisplay(results); // function to print result to 7-segment display
    // Calculate height difference between currPos and
    // new tide height. Value may be positive or negative depending on
    // direction of the tide. Positive values mean the water level
    // needs to be raised to meet the new predicted tide level.
    heightDiff = results - currPos;       // Units of feet.
    // Convert heightDiff into number of steps that must pass
    // to achieve the new height. The result is cast as an unsigned 
    // long integer.
    stepVal = (long)(heightDiff / stepConv);
    if (stepVal < 0) stepVal = -stepVal; // convert negative values


    //********************************
    // For debugging
    Serial.print("Height diff: ");
    Serial.print(heightDiff, 5);
    Serial.println(" ft.");
    Serial.print("stepVal calc: ");
    Serial.println(stepVal);
    Serial.print("Target height: ");
    Serial.print(results, 4);
    Serial.println(" ft.");
    Serial.println(); // blank line
    //******************************************************************
    // Motor movement section
    // ************** Lower water level to new position ****************
    // If the heightDiff is negative, AND the target level is less than 
    // the upperPos limit, AND the target level is greater than the 
    // lowerPos limit AND the lowerLimitSwitch 
    // hasn't been activated, then the motor can be moved downward. 
    if ( (heightDiff < 0) & (results < upperPos) & 
      (results > lowerPos) & (digitalRead(lowerLimitSwitch) == HIGH) )
    {
      digitalWrite(stepperEnable, LOW); // turn motor power on
      delay(100);      
      // Set motor direction to move downward
      digitalWrite(stepperDir, LOW);  // LOW = counterclockwise = down     
      // Run motor the desired number of steps
      for (unsigned int steps = 0; steps < stepVal; steps++) {
        digitalWrite(stepperStep, HIGH);
        delayMicroseconds(2);
        digitalWrite(stepperStep, LOW);
        delayMicroseconds(stepDelay);
        // check lowerLimitSwitch each step, quit if it is activated
        if (digitalRead(lowerLimitSwitch) == LOW) {
          // Calculate how far the motor managed to turn before
          // hitting the lower limit switch, record that as the new
          // currPos value.
          currPos = currPos - (steps * stepConv);
          Serial.println("Hit lower limit switch");
          digitalWrite(lowLimitLED, HIGH);
          break;  // break out of for loop
        }
      }
      delay(100);
      digitalWrite(stepperEnable, HIGH); // turn motor power off      
      if (digitalRead(lowerLimitSwitch) == HIGH) {
        // If the lower limit wasn't reached, then the currPos should
        // be equal to the new water level stored in 'results'.
        currPos = results;
      }
      digitalWrite(highLimitLED, LOW);  // highLimitLED should be off     
    }
    // ************Raise water level to new position******************
    // If the heightDiff is positive, AND the target level is greater 
    // than the lowerPos limit, AND the target level is less than the 
    // upperPos limit (plus a 0.1 ft buffer), AND the upperLimitSwitch 
    // hasn't been activated, then the motor can be moved.
    else if ( (heightDiff > 0) & (results > lowerPos) & 
      (results < (upperPos + 0.1)) & (digitalRead(upperLimitSwitch) == HIGH) )
    {
      digitalWrite(stepperEnable, LOW); // turn on motor power
      delay(100);      
      // Set motor direction in reverse
      digitalWrite(stepperDir, HIGH); // HIGH = clockwise = up
      // Run motor the desired number of steps
      for (unsigned int steps = 0; steps < stepVal; steps++) {
        digitalWrite(stepperStep, HIGH);
        delayMicroseconds(2);
        digitalWrite(stepperStep, LOW);
        delayMicroseconds(stepDelay);
        // check upperLimitSwitch each step, quit if it is activated
        if (digitalRead(upperLimitSwitch) == LOW) {
          // Since the upper limit switch is the "home" position
          // we assume that the currPos = upperPos when the
          // upperLimitSwitch is activated.
          currPos = upperPos;
          Serial.println("Hit upper limit switch");
          digitalWrite(highLimitLED, HIGH);  // turn on high limit LED
          break;  // break out of for loop
        }
      }
      delay(100);
      digitalWrite(stepperEnable, HIGH); // turn off motor power      
      if (digitalRead(upperLimitSwitch) == HIGH) {
        // If the upper limit wasn't reached, then currPos should
        // be equal to the new water level stored in 'results'.
        currPos = results;
      }
      digitalWrite(lowLimitLED, LOW); // Turn off low limit LED if it's on.   
    }
    // End of motor movement section. If the current tide ht is outside
    // either of the travel limits, then there should be no motor 
    // movement, and the currPos value should not be changed. 
    //*******************************************************************
    if (digitalRead(upperLimitSwitch) == LOW) {
      Serial.println("At upper limit, no movement");
      Serial.println();
      digitalWrite(highLimitLED, HIGH);
      digitalWrite(lowLimitLED, LOW);
    }
    if (digitalRead(lowerLimitSwitch) == LOW) {
      Serial.println("At lower limit, no movement");
      Serial.println();
      digitalWrite(lowLimitLED, HIGH);
      digitalWrite(highLimitLED, LOW);
    }
    // The lower limit is a bit more flexible depending on 
    // lower reed switch placement and lowerPos value, so if
    // tide height is less than lowerPos (but the carriage hasn't
    // reached the lower limit switch), go ahead and turn 
    // lower limit LED on to show user that we've reached 
    // the lower limit. 
    if (results < lowerPos) {
      digitalWrite(lowLimitLED, HIGH); // turn LED on
    }
	

	sevenSegDisplay(results); // function to print result to 7-segment display
	
  }    // End of if (now.minute() != currMinute) statement
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

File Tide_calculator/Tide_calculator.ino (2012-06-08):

/* Tide_calculator
  Copyright (C) 2012 Luke Miller
  
 This code calculates the current tide height for the 
 pre-programmed site. It requires a real time clock
 (DS1307 or DS3231 chips) to generate a time for the 
 calculation.
 
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
 
 This program is designed to calculate the current tide height
 and control a motor that changes the water level in a tank.
 
 Written under v1.0.1 of the Arduino IDE.
 
 The harmonics constants for the tide prediction are taken from 
 the XTide harmonics file. The original harmonics.tcd file is 
 available at 
 http://www.flaterco.com/xtide/files.html
 As with XTide, the predictions generated by this program should
 not be used for navigation, and no accuracy or warranty is given
 or implied for these tide predictions. Hell, the chances are 
 pretty good that the tide predictions generated here are 
 completely wrong.
 
 
 */
//********************************************************************************

// Initial setup
//*******************************
#include <avr/pgmspace.h>    // Needed to store values in PROGMEM
// Header files for talking to real time clock
#include <Wire.h>
#include <RTClib.h> // Available at https://github.com/adafruit/RTClib
// Real Time Clock setup
RTC_DS1307 RTC;      // This line remains the same even if you use the DS3231 chip
unsigned int YearIndx = 0;    // Used to index rows in the Equilarg/Nodefactor arrays
float currHours = 0;          // Elapsed hours since start of year
const int adjustGMT = 8;     // Time zone adjustment to get time in GMT. Make sure this is
// correct for the local standard time of the tide station. 
// No daylight savings time adjustments should be made. 
// 8 = Pacific Standard Time (America/Los_Angeles)

int currMinute; // Keep track of current minute value in main loop

//----------------------------------------------------------------------------------
/* Initialize harmonic constituent arrays. These each hold 37 values for
   the tide site that was extracted using the R scripts 
   'tide_harmonics_parse.R' and 'tide_site_extract_harmonics.R'. The 2nd
   script outputs a text file that contains code that can be copied and pasted
   into the section below. 
   If you wish to make predictions for a different site, it will be necessary to
   replace the Amp and Kappa values with values for your site. Either use the R
   scripts to get data for a new site, or get the new site values from NOAA.
   These are available from NOAA's http://tidesandcurrent.noaa.gov site.
   Kappa here is referred to as "Phase" on NOAA's site. The order of the
   constants is shown below in the names. Unfortunately this does not match
   NOAA's order, so you will have to rearrange NOAA's values if you want to 
   put new site values in here.
   The Speed, Equilarg and Nodefactor arrays can all stay the same for any 
   site. 
   
*/
//-----------------------------------------------------
// Begin pasted section from R script "tide_site_extract_harmonics.R"
// Selected station:  Monterey, Monterey Harbor, California 
// The 'datum' printed here is the difference between mean sea level and 
// mean lower low water for the NOAA station. These two values can be 
// found for NOAA tide reference stations on the tidesandcurrents.noaa.gov
//  site under the datum page for each station.
const float Datum = 2.8281 ; // units in feet
// Harmonic constant names: J1, K1, K2, L2, M1, M2, M3, M4, M6, M8, N2, 2N2, O1, OO1, P1, Q1, 2Q1, R2, S1, S2, S4, S6, T2, LDA2, MU2, NU2, RHO1, MK3, 2MK3, MN4, MS4, 2SM2, MF, MSF, MM, SA, SSA
// These names match the NOAA names, except LDA2 here is LAM2 on NOAA's site
typedef float PROGMEM prog_float_t; // Need to define this type before use
PROGMEM prog_float_t Amp[] = {0.071,1.199,0.121,0.023,0.038,1.616,0,0,0,0,0.368,0.044,0.753,0.036,0.374,0.134,0.016,0.003,0.033,0.428,0,0,0.022,0.011,0.041,0.072,0.026,0,0,0,0,0,0,0,0,0.157,0.09};
PROGMEM prog_float_t Kappa[] = {233.4,219.8,172,220.2,225.9,181.1,0,0,0,0,154.6,123.9,203.4,250.2,215.6,195.1,199.4,180.2,319.1,180.2,0,0,167.8,180.7,114.6,161.1,196.6,0,0,0,0,0,0,0,0,206,283.9};
// Speed is unscaled, stored as the original float values
PROGMEM prog_float_t Speed[] = {15.58544,15.04107,30.08214,29.52848,14.49669,28.9841,43.47616,57.96821,86.95231,115.9364,28.43973,27.89535,13.94304,16.1391,14.95893,13.39866,12.85429,30.04107,15,30,60,90,29.95893,29.45563,27.96821,28.51258,13.47151,44.02517,42.92714,57.42383,58.9841,31.0159,1.098033,1.015896,0.5443747,0.0410686,0.0821373};
PROGMEM prog_float_t Equilarg[10][37] = { 
{174.95,18.51,216.55,157.82,231.31,194.25,291.37,28.5,222.75,57,41.93,249.62,171.62,53.64,349.93,19.3,226.99,176.92,180,0,0,0,3.08,29.59,26.6,178.91,156.28,212.76,9.99,236.18,194.25,165.75,31.01,165.75,152.32,280.07,200.13},
{275.37,17.7,214.57,348.14,159.57,270.19,225.29,180.38,90.58,0.77,16.09,121.98,248.92,333.61,349.19,354.82,100.72,177.65,180,0,0,0,2.35,287.37,178.91,73.02,51.75,287.89,162.69,286.28,270.19,89.81,312.35,89.81,254.1,280.81,201.62},
{0.02,14.86,208.97,182.74,72.78,10.35,195.53,20.71,31.06,41.42,27.53,44.7,353.16,221.23,349.43,10.33,27.51,177.39,180,0,0,0,2.61,198.06,19.83,2.65,345.46,25.21,5.85,37.88,10.35,349.65,204.04,349.65,342.83,280.57,201.15},
{83.38,11.3,202.4,3.66,322.99,110.42,165.63,220.84,331.26,81.68,38.87,327.32,98.58,105.09,349.67,27.03,315.49,177.14,180,0,0,0,2.86,108.65,220.64,292.19,280.36,121.72,209.54,149.29,110.42,249.58,93.25,249.58,71.55,280.33,200.67},
{166.42,7.56,195.61,182.09,211.44,210.46,135.69,60.92,271.39,121.85,50.19,249.92,204.31,348,349.9,44.04,243.77,176.88,180,0,0,0,3.12,19.21,61.44,221.71,215.56,218.02,53.36,260.65,210.46,149.54,341.84,149.54,160.27,280.1,200.19},
{264.33,5.26,191.35,1.96,102.4,286.18,69.27,212.36,138.54,64.72,24.12,122.06,283.91,260.62,349.16,21.85,119.79,177.61,180,0,0,0,2.39,276.77,213.53,115.59,113.32,291.44,207.11,310.3,286.18,73.82,258.36,73.82,262.06,280.84,201.69},
{349.75,2.87,186.44,202.17,42.75,26.41,39.61,52.82,79.23,105.64,35.63,44.85,27.45,150.48,349.4,36.66,45.88,177.35,180,0,0,0,2.65,187.53,54.51,45.29,46.33,29.28,49.95,62.04,26.41,333.59,151.52,333.59,350.78,280.6,201.21},
{76.92,1.58,183.41,39.83,314.62,126.83,10.24,253.65,20.48,147.31,47.32,327.82,129.41,45.42,349.63,49.91,330.4,177.1,180,0,0,0,2.9,98.47,255.68,335.19,337.77,128.41,252.07,174.15,126.83,233.17,48,233.17,79.5,280.37,200.73},
{165.67,1.37,182.52,211.35,206.58,227.47,341.21,94.94,322.41,189.88,59.24,251.02,230.02,304.87,349.87,61.8,253.57,176.84,180,0,0,0,3.16,9.64,97.08,265.3,267.86,228.84,93.57,286.71,227.47,132.53,307.42,132.53,168.23,280.13,200.25},
{269.75,3.07,185.62,17.26,90.25,303.97,275.96,247.95,191.92,135.9,33.96,123.94,304.24,235.22,349.13,34.23,124.21,177.57,180,0,0,0,2.43,267.98,249.95,159.97,160.24,307.04,244.88,337.93,303.97,56.03,235.49,56.03,270.01,280.87,201.75} 
 };
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

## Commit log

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2012-05-03 Added code to calculate tide height using the harmonic constituents. Currently calculates for San Diego, CA, and is spot-on compared to tide predictions from NOAA and from XTide.
2012-05-03 A script to extract data for a single tide station from the harmonics data generated by the tide_harmonics_parse.R script. This script outputs code to the command line that can be copied and pasted i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
2012-05-04 Added code to remove current speed stations from the harmonics data to reduce potential ambiguities in finding tide stations by name, since this code is only focused on predicting tide heights, not c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
2012-05-04 Changed the initial declaration of the Equilarg and Nodefactor arrays to 2-D arrays that hold 4 year's worth of starting conditions. Larger arrays cause problems due to limited SRAM when the sketch i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
    [Tide_controller_v1_1.ino]
2012-05-04 Changed output to send code to a text file that can be copy/pasted into the Arduino sketch. This creates code to initialize the various tide prediction arrays needed in the Arduino sketch.
2012-05-06 Test code for actuating Pololu motor with encoder. Required modifying both the SoftwareSerial library and Pololu's PololuWheelEncoder library to get them to play nice together. The details are explai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
2012-05-07 Started adding real time clock code, got sidetracked and instead switched to Motor_encoder_scratch2.ino. Updated setup instructions at bottom, PololuQik.h must also be modified, and the original Soft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
2012-05-07 Added real time clock code, motor now actuates only on the 10-second time marks. This is a precursor to eventually calculating a new tide height once per minute (or maybe 5 minutes) and then actuatin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
2012-05-07 Added code to calculate current year and hours since the start of current year.
2012-05-07 Added code to calculate current tide height once per minute. Need to check that timezone stuff is working still.
2012-05-08 Commented out clock reset code in setup loop, this is probably best left to a separate sketch.
    [Tide_controller_v1_1.ino]
2012-05-09 Inserted new integer-based constants into setup section. Still need to adjust main loop code to convert integers back to real values.
2012-05-09 Added integer version of R script for generating the harmonic constants C code that is pasted into the Arduino sketch.
2012-05-09 Switch station to Monterey to check output. Predicted tides agree with NOAA website.
2012-05-09 Re-instated the PololuQik and WheelEncoders libraries and initialization during setup. The sketch still predicts tides correctly. No motor actuation is enabled yet.
2012-05-10 Started adding in code to calculate height difference and move motor up or down. Need to finish adding code to keep track of minutes and only allow one move per minute.
2012-05-11 Added code to keep track of current minute and change motor position up or down depending on new tide height. All code seems to work currently. TODO: Add limit switch routine for initialization at st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
2012-05-11 Moved motor shut-off command outside of pin change counting while loop, since I suspect the motor shut-off if statement might have be causing counts to be missed.
2012-05-20 Started v1.3 with external interrupts
    Began laying out v1.3 of the tide controller. The
    previous version 1.2 mostly works as a proof of
    concept, so I'm leaving it as-is.
2012-05-20 Inserted new encoder counting code
    Switched program to use external interrupt on digital pin 2
    to count motor encoder pulses. This involved major changes to
    the initialization, setup loop, and main loop. Still need to
    actually test this.
2012-05-20 Added code attribution for interrupts
    Forgot to include the reference to the external interrupt
    code. Updated now.
2012-05-21 Tested code -no improvement
    The new external interrupts didn't appear to improve accuracy
    with the motor. It's not clear to me if the interrupt routine
    is missing counts, or if I've screwed up the math somewhere
    along the line. It appear to be missing 20-40 triggers, so that
    even a short 10-15 count movement is turning an extra 16-32
    counts (without registering those counts in the total).
2012-06-01 Created v1.4 to use stepper motor
    The older versions used a normal electric motor with encoder,
    but the encoder counting routines often missed counts, leading
    to errors in position. This version will use a stepper motor to
    try to improve the accuracy of movements.
    [Tide_controller_v1_4.ino]
2012-06-01 Commenting out old code
    Removing the pololu motor controller code and external
    interrupt routines.
2012-06-01 Inserting stepper motor setup
    Starting to include the pin assignments and comments
    for driving a stepper motor via the Big Easy Driver.
    Still need to implement the motor turning in the main
    loop and also adjust the distance conversion factor for
    converting steps into linear distance.
2012-06-02 Inserted stepper motor control code
    Also removing some older motor control code. Motor should
    now turn the correct number of steps to move to the new tide
    height.
    [Tide_controller_v1_4.ino]
2012-06-03 New stable prototype
    Testing overnight to see how accurate the distance keeping is.
    It currently gets from the starting point to the current tide
    level with about 1 inch of error, which is most likely due
    entirely to the changing diameter of the spool as line feeds
    off.
    [Tide_controller_v1_4.ino]
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2012-06-03 Moved date,time serial printout to sub-function
    Also re-arranged the pre-amble for readability and
    removed some older commented-out code.
2012-06-04 Inserted code to return to home position
    Added a while loop in the setup loop to bring the sled
    position back to the home position at the upperLimitSwitch.
    This will run until the upperLimitSwitch is activated. This
    gives the program a constant starting position on each
    reboot.
    [Tide_controller_v1_5.ino]
2012-06-04 Switch fundamental logic of heightDiff
    Changed the sign (plus/minus) of the heightDiff
    calculation. Now the value will be positive if the
    water level needs to increase (tide is rising) and
    negative if the water level needs to drop (tide is
    dropping). Still need to implement the limit switch
    logic.
2012-06-04 Implemented new logic tests for moving motor
    The decision to move the motor now relies on checking
    that the new target position is within both the lower
    and upper limits of the rack, and that the appropriate
    limit switch hasn't already been activated.
    Also modified the conversion factor for distance per
    motor step to work with the 10tpi lead screw.
2012-06-04 Shifted limit values
    The upperPos and lowerPos values can be shifted so that you
    end up with a height window that encompasses the current
    tide height. This makes initial trouble-shooting quicker than
    waiting for the tide to enter your actual tide range.
2012-06-04 Adding comments, changed lower limit logic
    Changed the lower limit switch logic so that the last
    position stored when the lower limit switch activates is
    the actual distance traveled from the upper limit, not
    the hard-coded lower limit value (in lowerPos). This is
    because the magnetic switch position is often imprecise, so
    one of the two switch positions needs to be taken as
    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
2012-06-04 Fixing more formatting, no code changes
    [Tide_controller_v1_5.ino]
2012-06-04 Added some more debugging output to serial monitor
    Notifying user when the motor is at either of the
    travel limit switches.
2012-06-04 Fixed type in debugging output
    Switched upperLimitSwitch to lowerLimitSwitch. Oops.
    [Tide_controller_v1_5.ino]
2012-06-07 Fixed year index bug
    Swapped order of YearIndx calculation so that future years
    will produce the correct array index for accessing the
    Equalarg, Nodefactor, and startSecs arrays.
    [Tide_controller_v1_5.ino]
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2012-06-08 Initial version of tide calculator
    This is just a stand alone tide calculator. It doesn't
    do anything besides spit out a current tide height to
    serial every minute. It's just an example of the tide
    calculation components.
    [Tide_calculator.ino]
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2012-06-08 Switched harmonics to float values
    Trying to reduce the complexity of the code by
    removing the integer-conversion steps for the tidal
    harmonic constituents now that I no longer need to save
    the memory space. Tide output is still accurate.
    [Tide_controller_v1_6.ino]
2012-06-08 Removed integer conversion code from tide calcs
    Since the harmonic constituents are now being stored as float
    values in PROGMEM, it's no longer necessary to convert them
    from integers to floats during the tidal height calculation.
    This simplifies the code slightly and improves readability.
    [Tide_controller_v1_6.ino]
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2012-07-16 Fixed bug related to abs() function
    The abs() function/macro/whatever treats every input as an
    int if you have both the SPI.h and SoftwareSerial.h libraries
    included. Replaced it with an if statement.
    [Tide_controller_v1_9.ino]
2012-07-17 Adjusted shore height limits, lower limit was too low
    for the rack as currently set up.
    [Tide_controller_v1_9.ino]
2012-07-17 Implemented ENABLE line on stepper driver
    The Big Easy Driver has an enable line that can be used to
    shut down power to the stepper motor when pulled high.
    Because the lead-screw design of the rack holds position when
    the motor is powered off, I can use the enable line to shut
    down the motor between movements and thereby reduce the heat
    production of the Big Easy Driver and the motor. It has the
    added side effect of reducing the whining noise that came from
    the driver at idle. This cuts the idle temperature of the driver
    chip from approx 75C to 35C, since it's off most of the time.
    [Tide_controller_v1_10.ino]
2012-07-23 Adjusted upper limit buffer
    Need to allow upward travel to continue further until the
    upper limit switch is hit, in case steps are missed during
    the upward travel cycle (due to heavy loads and stalling).
    [Tide_controller_v1_9.ino]
2012-07-26 Adjusted upper shore height test in movement code
    Needed to add a larger buffer to the upper tide height limit
    when moving the carriage upward, in case a heavy load causes
    some steps to be missed. This should allow the carriage to reach
    the upper limit switch and properly re-home itself.
    [Tide_controller_v1_10.ino]
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2012-07-31 Fixed lower limit switch logic in override code
    Added some comments, enabled and tested the override code.
    [Tide_controller_v2_0.ino]
2012-07-31 Changed pin assignments for rev6 daughterboard
    The override button is now on pin D13. The Big Easy Driver
    ENABLE pin is now tied to pin D12. These changes allow operation
    with the tide controller daughterboard revision 6.
    Need to alter setup loop to lower carriage to correct
    starting spot after homing. If user plugs in tide controller while
    the current tide height is below the programmed lower limit, the
    program gets stuck with both high and low limit LEDs on.
    [Tide_controller_v2_0.ino]
2012-07-31 Modified setup loop to move carriage to position
    The setup loop now has code to move the carriage to the
    current tide height after initially moving the carriage up to
    find home (upper limit). This avoids situations where the
    unit is powered up while the real tide is below the lower
    travel limit and the program would hang.
    [Tide_controller_v2_0.ino]
2012-07-31 Added more logic to setup loop
    Forgot to add code to reset current position to the tide
    height if the motor moved the carriage down, but didn't reach
    the lower limit switch. Now it should work.
    [Tide_controller_v2_0.ino]
2012-07-31 Fixed variable type issue in setup loop
    Changed for loop variable to unsigned long to accomodate
    the large number of steps that would accumulate in moving
    the carriage down to the starting position. This should fix
    any issues with powering up when the tide is below the lower
    travel limit.
    [Tide_controller_v2_0.ino]
2012-09-08 Updated library generation script
    The new library generation script deals with multiple site matches and
    lets the user choose the correct one. The output tide prediction
    library includes an example sketch for the Arduino.
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2015-03-20 Code for new 2ft travel version, where upper limit sensor has been moved down the rack rail to sit 2.0ft (24inches) above the lower limit sensor. Tide height has been set so that the upper limit corr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
    [Tide_controller_v2_5.ino]
2015-03-26 Fixed sevenSegDisplayTime function where I wasn't calling now.hour() and now.minute() correctly, and changed a mySerial.write(0x00) command to mySerial.print(0); since it wasn't compiling correctly.
    [Tide_controller_v2_4.ino, Tide_controller_v2_5.ino]
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2022-02-18 Hardware files put into their own directory
    [Tide_controller_shield_v1.brd, Tide_controller_shield_v1.sch]
2026-02-11 Fix some parentheses, update date
    [Tide_controller_v2_6.ino]

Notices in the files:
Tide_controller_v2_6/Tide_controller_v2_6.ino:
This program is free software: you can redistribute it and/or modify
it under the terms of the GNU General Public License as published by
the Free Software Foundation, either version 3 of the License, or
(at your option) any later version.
